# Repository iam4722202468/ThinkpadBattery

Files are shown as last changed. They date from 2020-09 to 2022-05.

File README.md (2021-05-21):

# ThinkpadBattery
Open source Thinkpad battery design

## What is this?

This is a fully open source laptop battery design. The design uses an attiny85, which can reply to the T420 motherboard's SMBUS requests.

## Setup

### Configurable Constants

- BATTERY_CAPACITY | Your battery capacity in mAH
- V_HIGH | The highest output voltage of your battery, normally 12.6v
- V_LOW | The cutoff for when the battery will stop working, normally around 10.8v

### Creating your own

Parts Needed
- Arduino Uno/Mega  (for programming the attiny85, Mega needs different pin assignment)
- 12v Lithium-Ion battery pack
- 3S Lithium-Ion BMS (it might be possible to use the existing bms if specification is available but communication needs to be implemented)
- Components from schematic
- PCB from schematic

Once you have all these parts, assemble the pcb and attach a BMS to your battery pack. Solder the 12v battery output/input to the large pads on the pcb, then program the attiny85 with the included ino file. The output pins at the bottom of the PCB are a 1-1 mapping of the motherboard pin input.

### Debugging

- The laptop won't supply power to the board unless it detects there's a battery attached, meaning if you plug the board in to the battery without having an external battery to power it, it won't work.

### Libraries

Use the ATTinyCore for compiling. Without it, Wire.h won't work.

## Limitations

### Voltage Reading / Remaining battery

Currently remaining battery %'s aren't exact because I'm assuming there is a linear coorelation between voltage and capacity (Which is wrong). This is probably fixable using a battery gas gauge, I'll have to investiage more.

### MCU Power Consumption

By design, the MCU will always be on as long as a battery is connected to it. This can cause the battery to slowly run out of power if it isn't connected to a laptop. A potential fix could be to implement a low power mode for the attiny, or have a seperate disconnect switch for the battery power on the battery pack itself.

### 3D Printable Case for T420 only

The case for the cells has been completed. The case model and stl files are included in /model

## Future Plans

iam4722202468 - Design and manufacture a PCB with current,voltage and battery capacity measuring capabilities, an easily programmable microcontroller, and a 3s balanced charger

pj1976 - Find a bms that would fit, or try to talk with bq29312pw that was in the original pack

## Credits

iam4722202468 - Initial work, T420 9 cell model

pj1976 - Added support for R50

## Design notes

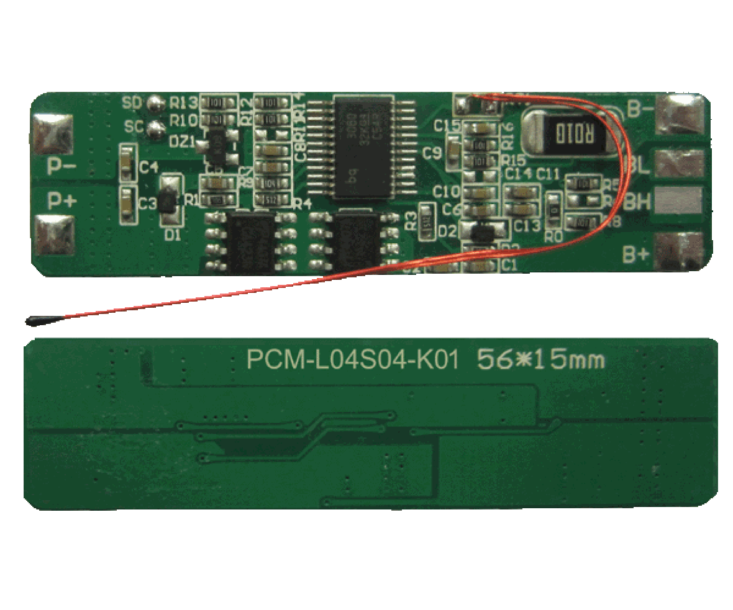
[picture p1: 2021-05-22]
KiCad/bq3060/references/r1.gif

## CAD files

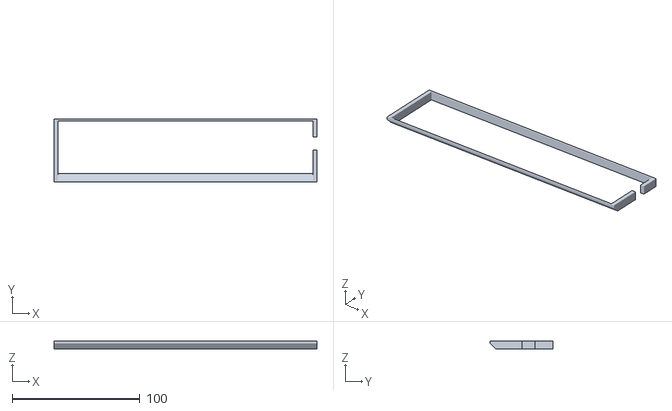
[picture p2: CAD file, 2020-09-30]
model/top_case_long.stl
206.0 x 49.0 x 6.50

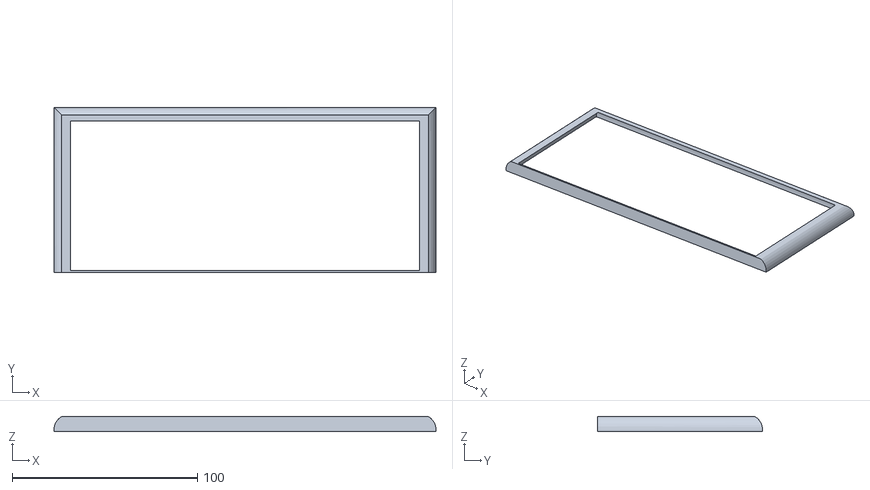
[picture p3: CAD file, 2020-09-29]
model/bottom_case_long.stl
206.0 x 89.0 x 8.00

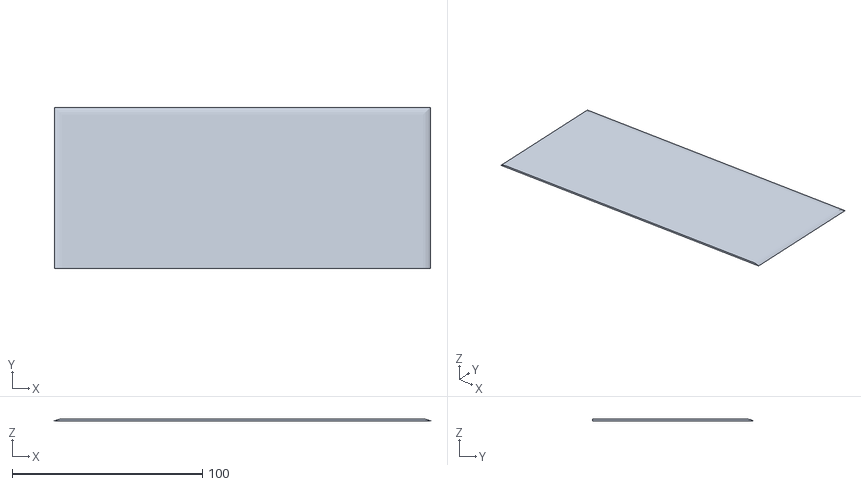
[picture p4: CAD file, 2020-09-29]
model/bottom_case.stl
197.7 x 84.9 x 1.00

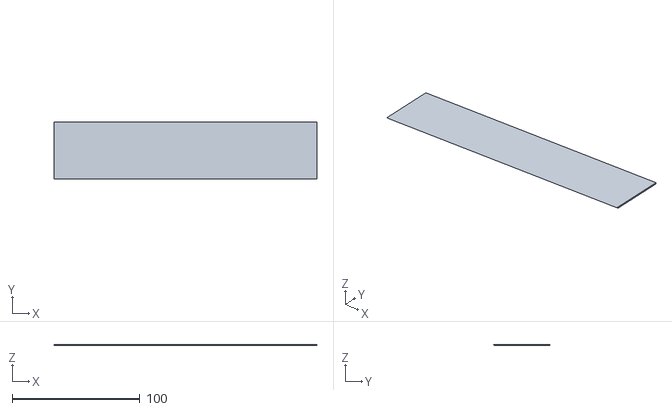
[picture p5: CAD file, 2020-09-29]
model/top_case.stl
206.0 x 44.5 x 1.00

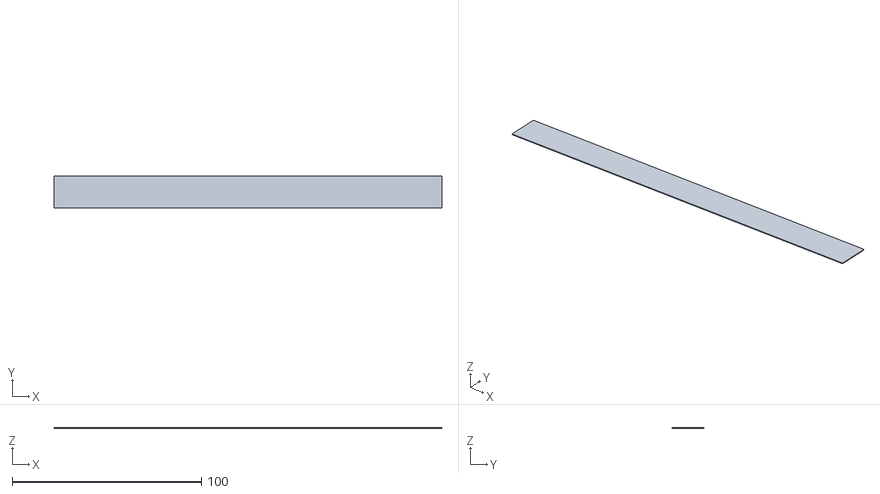
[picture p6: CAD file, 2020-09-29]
model/bottom_holder_thin.stl
205.0 x 17.0 x 0.4

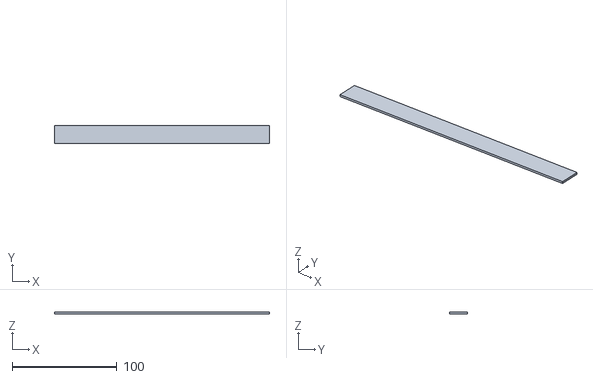
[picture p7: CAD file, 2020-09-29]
model/bottom_holder_thick.stl
205.0 x 17.0 x 1.60

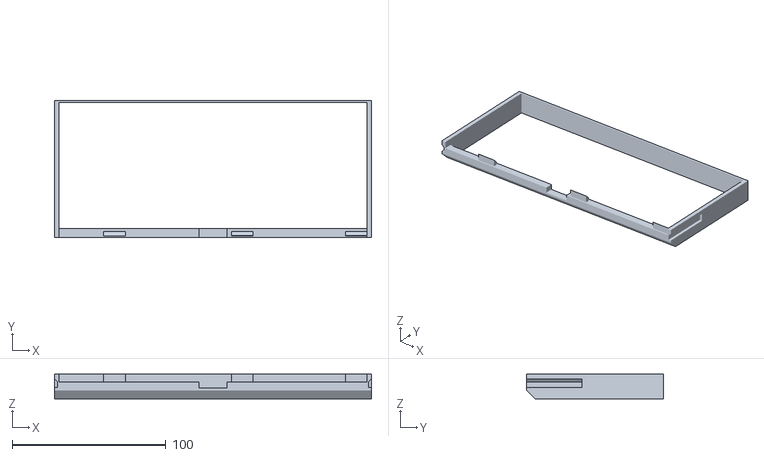
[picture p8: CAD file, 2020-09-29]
model/back.stl
206.0 x 89.0 x 16.0

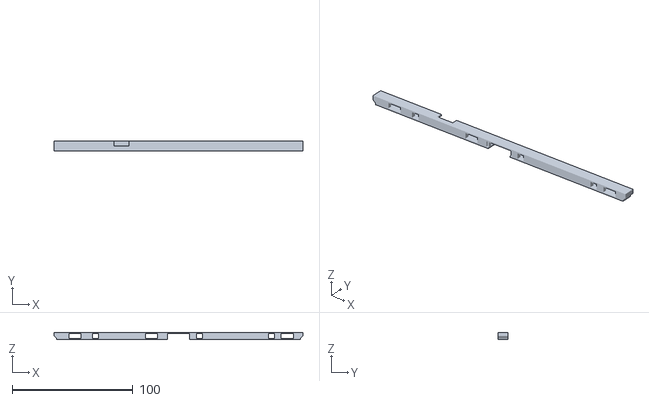
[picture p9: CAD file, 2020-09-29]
model/front.stl
206.0 x 8.00 x 6.00

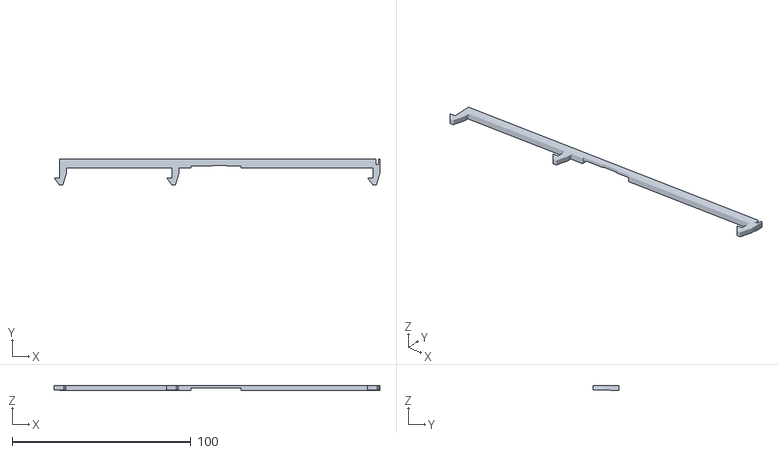
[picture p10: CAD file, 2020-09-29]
model/lock.stl
182.5 x 14.5 x 3.00

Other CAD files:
model/case.FCStd

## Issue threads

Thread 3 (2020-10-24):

Problems verifying .ino sketch

develroo, 2020-10-24:
Hi. First I want to say thanks very much for this project because it fits my need almost perfectly. I am trying to emulate a battery to power a laptop by a DC power supply. Once you have a suitable resistance for Thermal overload it will power on and stay on so long as the OS is not fussy about battery status and power down thinking the battery is broken. This is where your project comes in.

However I downloaded your batteryEmulator.ino but it fails to verify or compile

```
Arduino: 1.8.13 (Linux), Board: "Digispark Pro (Default 16 Mhz)"

/home/user/devel/git/ThinkpadBattery/batteryEmulator/batteryEmulator.ino: In function 'void setup()':
batteryEmulator:523:19: error: no matching function for call to 'USI_TWI::begin(int)'
   Wire.begin (0x0B);
                   ^
/home/user/devel/git/ThinkpadBattery/batteryEmulator/batteryEmulator.ino:523:19: note: candidate is:
In file included from /home/user/devel/git/ThinkpadBattery/batteryEmulator/batteryEmulator.ino:1:0:
/home/user/.arduino15/packages/digistump/hardware/avr/1.6.7/libraries/Wire/Wire.h:57:13: note: void USI_TWI::begin()
     void    begin();
             ^
/home/user/.arduino15/packages/digistump/hardware/avr/1.6.7/libraries/Wire/Wire.h:57:13: note:   candidate expects 0 arguments, 1 provided
batteryEmulator:524:8: error: 'class USI_TWI' has no member named 'onReceive'
   Wire.onReceive (receiveEvent);
        ^
batteryEmulator:525:8: error: 'class USI_TWI' has no member named 'onRequest'
   Wire.onRequest (requestEvent);
        ^
exit status 1
no matching function for call to 'USI_TWI::begin(int)'

This report would have more information with
"Show verbose output during compilation"
option enabled in File -> Preferences.

```

I don't know much about your environment but am I missing something in mine?

Edit: For reference I do include the TinyWire lib.

```
#include <USI_TWI_Master.h>
#include <TinyWireM.h>

#include <Wire.h>
```

Thanks

digmorepaka, 2020-10-24:
try using wire.h only and attinycore instead of digistump. i had this same issue and that resolved it

iam4722202468, 2020-10-30:
digmorepaka is correct, based on your error log it looks like you need to use attinycore.

develroo, 2020-11-03:
Yeah fixed and I compiled the code alas it was not a drop in replacement for my battery/laptop. I don't have the time to reverse engineer the protocol unless you can do it with the batter alone because I have already seconded the laptop into it's 1U case and put it in the cabinet. I can still boot Linux so long as I use `acip=off` which is ok but that also affects the fans if I am not very much mistaken so.

Wish I had the time and tools to debug the communication but alas I have neither atm.

Thanks anyway it is a great resource and I will think about getting a data analyser anyway just for the next time I run into something like this.

Cheers!

Closed 2020-10-30.

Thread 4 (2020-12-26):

universal battery emulator?

5ch4um1, 2020-12-26:
Hello young gentleman!
First of all, thank you very much for your excellent work!
I was wondering if you realize that your sketch is basically an implementation of the SBS for arduino? I mean, Thinkpads are by far not the only devices that use TI controllers, and your sketch should be really easy to adapt to other arduino platforms and most important: other batteries and devices!
I did some first tests today, it seems to crash when you ask for and address that is not defined, but most of the things my laptop wants to know are already defined. btw, any interest in maybe making a wiki with explanations for all the values? like, 3b-3f looks like cell voltages,  1c is the serial number, etc... i was going to read some pdfs again these days that start with sluu, but wouldn't it be nice to have this information in a more human readable format, without all the scrolling, like a simple table maybe? I was able to capture the communication with my dead but still talking ideapad battery, so i know what it will be asking for.
The ability to simply make up certain values seems very practical for testing!
I was wondering, how do you tell the system that a battery is present, when it's not? resistor between + and - should do i guess?
And how about adding a temperature sensor instead of hardcoding 22,1 ºC, i mean, it's an arduino? And maybe add some logic that doesn't charge when the temperature is too high?

iam4722202468, 2021-01-18:
Hey!
Yeah, this is basically an implementation of the SMBus for an attiny controller. Thanks for letting me know about the crashing, about a week ago I was thinking about this code and realized that crashing might have been a problem when it got requests that weren't defined, but wasn't sure.

> I was wondering, how do you tell the system that a battery is present, when it's not? resistor between + and - should do i guess (edit: seems like a 10kohm resistor between the thermistor and ground does the trick.)

Sounds right. Interestingly, I noticed that the cheap third party battery I took apart uses a 10k resistor on the temperature sensor pin too.

> And how about adding a temperature sensor instead of hardcoding 22,1 ºC, i mean, it's an arduino? And maybe add some logic that doesn't charge when the temperature is too high?

Another good idea, it would definitely be possible, would be easy to add, and there's free pins that aren't used for anything on the attiny right now.

The long term plan is to make this an open platform for all old batteries, where there's one pcb that can be programmed to work with any laptop. Right now I'm taking a bit of a break from this project while I wait on a bunch of attiny pcb's to be manufactured, once those come in I'll continue doing more testing. Have learned a lot about this since I started the project, hopefully I'll be able to expand on what I've already posted soon.

5ch4um1, 2021-01-19:
Well, also not limited to attiny, i tried with an arduino nano clone and it worked, and i could imagine that this will work on a lot of other platforms too ;)
And for the temperature sensor, "A thermistor is a temperature sensitive resistor..." so 10kohm means something around 21º C iirc. Would probably be possible to recycle one from an old battery pack and use it with the microcontroller.
I wonder if the temperature is measured by both the battery and the laptop? I mean, the battery for sure, but the laptop has that pin, so i guess it somehow uses it?
Anyway, i'd definitely recommend to keep a simple version around as the project grows, for educational and testing purposes it seems very practical as it is at the moment.
speaking about old batteries, do newer devices have some kind of authentication mechanism for normal operation mode?
Newer devices seem to have secure auth to get them into unsealed or full access mode, but i haven't heard of anything like this for normal operation mode?
Anyway, there is a huge potential in this, this is literally power to the people!
thank you very much.

iam4722202468, 2021-01-20:
> do newer devices have some kind of authentication mechanism for normal operation mode
Yeah, this is a bit of a problem, quite a few devices require the correct reply from the auth command. The T430 actually has an auth command, where an incorrect reply will stop the battery from charging.

One of the benefits on using an attiny instead of a conventional SMbus IC is that they're easy to program, and in the future if exploits or workarounds are found for the auth sequences it's super easy to update and test the code. Some manufactures also implement custom commands, and again for the same reasons using an attiny here can simplify things.

TheWorldIsBetterWithElectronics, 2021-07-23:
Hello,
This is a very interesting project. You did a hell of a job. Thanks you. But could you reediter the code with a little more comments so that it is more understandable because I am not a code genius. Because I would like to modify the project so that it adapts to my computer but I quickly get lost in all these lines. Thank you if you have some time to help me to understand the code.

iam4722202468, 2021-07-23:
@TheWorldIsBetterWithElectronics
> Hello,
> This is a very interesting project. You did a hell of a job. Thanks you. But could you reediter the code with a little more comments so that it is more understandable because I am not a code genius. Because I would like to modify the project so that it adapts to my computer but I quickly get lost in all these lines. Thank you if you have some time to help me to understand the code.

Thanks for the feedback! I added some comments to explain what's going on in the code, hopefully that helps you.
For future reference, it's generally better to create a separate issue for new requests as it makes it easier for the developer to find the message and helps you more easily track work done.

TheWorldIsBetterWithElectronics, 2021-07-23:
Thanks for the improved code feedback, it's still easier to understand the big parts of the code now. I will continue to experiment with the battery of my computer and I will tell you if it works or not. I will probably come back to ask questions but now, I will not forget to create a new  issue . Thank you very much.

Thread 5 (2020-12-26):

gap between request and answer?

5ch4um1, 2020-12-26:
Not a real issue, seems to work anyway, i just noticed that the arduino takes a bit longer to answer (roughly 420 microseconds) than the original battery, here the arduino (nano clone):
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

and here the original:

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
is that maybe the time it takes to calculate the pec, or why is this happening?

digmorepaka, 2020-12-27:
Not sure if it's related, but apparently if you have the Arduino bootloader flashed the atmels tend to be slower in certain operations, does this occur when flashing the compiled binary over icsp while ommiting Arduino bootloader etc

5ch4um1, 2020-12-27:
you mean cross compiling it with avr-gcc and flashing it with avrdude? no, haven't tried this yet. and actually this looks a bit complicated for the newbie that i am. and again, it works anyway, the delay seems to be within what's acceptable for the laptop.
I think i have like a million questions, is there maybe a thread in a forum, subreddit, discord, or anything like that?
Anyay, i tested today with my Ideapad G550 and so far it seems to work pretty much "out of the box", though it won't accept any other vendor name than the original, defaults to COMPAL otherwise:
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

iam4722202468, 2021-01-18:
Haven't done any testing for this yet, but if the delays are consistently the same length for all the packets I suspect the attiny is just taking a while to process the input and create the output.

iam4722202468, 2021-01-19:
@5ch4um1 if you want to ask questions, I'm on the thinkpad discord with a bunch of other people who would be happy to answer them! https://discord.com/invite/Ybdz7AS

5ch4um1, 2021-01-19:
Thanks again, very much appreciated.
And i don't know, i tested with an arduino nano clone, could test now again with a wemos d1 mini, don't have a second logic analyzer to see if maybe something was wrong with that part of my setup, but as mentioned, it works anyway. I may or may not have posted this issue just to point out that the gap was 420 microseconds... ;)
Closing for now, will reopen if it turns out to be a real functional issue.

Closed 2021-01-19.

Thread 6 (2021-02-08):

Help me please. The voltage of 12367mV is displayed all the time, it always shows 100% of the charge

Naughtydog2004, 2021-02-08:
Hello. Can you please tell me which command controls the battery state of charge at 100% and charge / discharge mode? I can manage charge percentages with the byte reply0x0D command. But my laptop still shows 100% and won't charge the battery. By the way, the voltage from the resistor divider also does not change in any way and is transmitted to the SMBus as 12367mV (although, separately from this program, the code for measuring the voltage functions properly through the analog pin A3 on the arduino nano). Thanks in advance.
https://drive.google.com/file/d/1x5DdUYXAxN2JYD1_1s9keKdGmnjLt5Kj/view?usp=sharing

iam4722202468, 2021-02-10:
Looking at my code, it looks like reply0x0F is what handles the % charged, try manually setting the charge value to something and checking if that changes the charge of your device. If it doesn't, then your device might need other packets than just the 0x0D one. Not all implementations of the smbus are identical for all devices

iam4722202468, 2021-02-10:
As for the voltage divider, there's a chance I screwed something up and it doesn't actually work, really hoping that isn't the case though... either way, i'll probably redo a few parts of this in around 4 months from now. The idea is to make a small pcb with a 3s bms and attiny combined, that can be programmed for any device.

Naughtydog2004, 2021-02-10:
Thank you! If I can fix this, then I will inform you

luketimothyjones, 2022-05-13:
I think `0x0f()` is incorrect, unless the Thinkpad battery departs from the SMBus spec (which is entirely possible). Command `0x0f` is `RemainingCapacity()`, which is expressed as mAh or mWh depending on the value of `0x03` bit 15 (aka `CAPACITY_MODE`): `0` for mAh and `1` for capacity/10 mW/mWh. The calculation in `0x0f` is identical to `0x09` (`Voltage()`)above it, perhaps it was a copying mishap?

iam4722202468, 2022-05-14:
@luketimothyjones yes this does look like an issue. When making this I didn't really know what I was doing, and it looks like I did just copy it. Feel free to pr a fix

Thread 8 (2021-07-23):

Add comments to batteryEmulator.ino

iam4722202468, 2021-07-23:
The code may be hard for some people to understand, comments would be helpful to have.

iam4722202468, 2021-07-23:
Fixed in commit a405590499ceca53eaf2dc03386848951c07be7e

Closed 2021-07-23.

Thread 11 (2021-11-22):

SMBUS Communication Stops Wehn Grabing Battery Vender on Emulated Battery

Sam64-png, 2021-11-22:
Hi, I am trying to power a A485 think pad from my lab bench power supply and uploaded this code onto an Arduino Nano. I have it all wired correctly and it successfully communicates with the Arduino. I changed the battery reference voltage to 5 volts, set the analog pin to A3 and A3 is reading around 4.4 volts. When powering the laptop it never turns on but some of the i2c commands and found that it never gets to the point were it reads the voltage but stops once it reads the vender. Here is a log of all the commands sent.
`0x03 0x15 0x18 0x19 0x1A 0x1B 0x1C 0x20`. I kept the vender in the code to the default value "HACKED". I do not have a good way to test the laptop on a working battery. What happened is that its charging circuitry got destroyed so I had to desolder some parts for it to come on. Now when i plug in a almost dead battery it turns on but dies a few seconds later.

Also I tired to get the vender from the original battery but it seems to reply with 0xFF for everything.

I have to thank you a lot seance this code is a life savor seance i don't want to spend a lot of money to get a new one and I don't like throwing out a whole computer when only one part fails. I really hope you can help. Once i get this done i plan to make a custom pc with it and a type c connector and battery to get a lot of the old functionality back.

iam4722202468, 2021-11-24:
Please keep in mind that batteries are dangerous, and this project is meant to be used with a bms, it is not a replacement for a bms. If you're directly connecting the cells to the circuit that could be the problem

Sam64-png, 2021-12-01:
>

Sorry I probably did not explain it too well. I was using the project without any battery so I could power the laptop from a bench power supply threw the battery connector. I tied the battery voltage detection analog pin to a adjustable voltage reference for testing.  Also in the mean time I am assuming the laptop stops communicating with the battery because it may be checking the vender id to stop agent cheaper off brand batteries. I been trying to get the vender id from a preexisting think-pad battery using the same commands from the code. It responds to that IC2 address but always replys with 0xFF. I don't have a logic analyzer directly intercept its communications so i may have to wire something up there. If you know what is wrong in the arduino code causing this setup or model of laptop to mess up any help is greatly appreciated.

iam4722202468, 2022-01-04:
@Sam64-png Sorry for taking so long to reply!

You are correct in saying that some batteries expect verification codes, it looks like the A485 model came out recently and most laptops newer than the T420 series do have verification. The verification will not be possible to get around without some exploit or a modified EC firmware, and I don't think either of those exist for that laptop (yet).

The reason you can't simply send the same responses is because the motherboard most likely sends the battery a challenge-response test, which involves a message being sent from the motherboard to the battery, the battery signing the message with a private key, and the motherboard verifying the signature with a public key. Without the private key there's no way to get the battery to charge

I'm sorry to hear that your charging circuitry got destroyed, that's unfortunate.

There's a chance that the program is crashing, this can happen with the motherboard sends a packet type that isn't recognized. You could check this by using an arduino with serial output like an arduino uno, modifying the code to log the packets that it receives, running the code and checking if there are packets sent that don't appear in the code. That being said, even if you get a little bit more communication working between the battery and the motherboard you will never be able to get past the auth sequence.

Good luck with your future projects!

Sam64-png, 2022-01-04:
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

Alright sounds good. I expected something in that case seance I felt they would of changed that later on so people buy the more expensive batteries. I went ahead and got a new laptop. Idk if I trust the chargers or at least the old one I had because i am wondering if that is what caused the issue with the charging in the first place. I had one break a while back and never investigated why it was broken seance their assembled into a solid brick, but I wonder if it was caused by the capacitors going bad and it is generating an unfiltered output with voltage spikes. Thank you for the help.

luketimothyjones, 2022-05-02:
> There's a chance that the program is crashing, this can happen with the motherboard sends a packet type that isn't recognized.

For historical reference, this was resolved by #12

Closed 2022-01-04.

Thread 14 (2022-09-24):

PLEASE MAKE FOR LENOVO X220

jakevin99, 2022-09-24:
I am planning to recell my 9 cell x220 battery but problem is the chip inside.

iam4722202468, 2022-10-07:
This will probably work on the x220 without any changes

iam4722202468, 2023-11-27:
> But will it work on **30 models?

Nah, unmodified the **30 models use a signature packet between the battery and laptop to ensure the laptop is authentic. No way around this, as message replies cannot be validated without having the key. There is [this](https://github.com/hamishcoleman/thinkpad-ec) project which you can use to remove the signing and make the battery work.

Michal-Szczepaniak, 2023-11-27:
What if i have corebooted **30 model? Then it will work?

iam4722202468, 2023-11-27:
Coreboot itself is only a modification for the bios. The EC (Embedded Controller) is what communicates with the battery, and is what needs to be modified.

Michal-Szczepaniak, 2023-11-27:
gotcha

Bromiun, 2023-11-28:
Isn't there a practical way to get around this problem?  A pack is usually 3S2P.  And let's say you have 6x 18650s to replace.

Charge the pack and 6 good cells to full.  Solder (with wires) 3S of the good cells to the existing two power strips and two balance strips in the pack.  This will keep the handshake trap happy.

Remove 3S of the bad cells.  Replace with good cells.  Either soldered or spot welded.

Remove the 2nd set of 3S bad cells and replace with the first 3S of good cells.

I believe that it is sufficient for one cell to go bad, to make the battery pack useless.  So test the 6 bad cells and you may find a few still operational.

iam4722202468, 2023-11-28:
That is possible, but it requires having a working battery. The goal of this project is to create a working battery from scratch.

Bromiun, 2023-11-29:
Yes, a valid point.  During my 15 years having multiple ThinkPads, I have accumulated a lot of packs with bad cells.  Buying packs off eBay is a possibility and my last purchase I believe about $50 is fantastic.  I used to open the packs up and replace the cells straight.  I soon discovered that is a good way to destroy a pack.

At one time, the laptop male connector got misaligned, and due to a defect in the design, when you push in the battery, it even clicks giving you a false sense that connection has been made. I could not get any pack to work and there was no mention of this issue in any forum.  I went through 3 or 4 packs the discover the problem and simple aligned the connector and it has been working to this day.. So I have a few working packs.  The design problem is that the female connector on the pack is spring loaded.  So it does not have to mate with the male terminal to insert the pack, and you can still push it in and force a false positive click.

I am sure you can find cheap packs that have bad cells but are still alive.  Have you tried this?

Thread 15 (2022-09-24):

Arduino Uno pack

Bromiun, 2022-09-24:
Hi Iam, I am new to Github, so am not sure how to connect with you.  This may not be the correct manner.  Please let me know.

I want to connect my 3s5p 2170 pack to my T540.  This will be in a box along with an Uno, separate from the laptop.  There will be no PCB.  There may be a 2x40 LCD to report on usage, V, Wh, etc.  No need to inform the T540 on the status.  BMS and protection and charging all in the box.  This will be the simplest method to defeat Lenovo's anti-consumer lock.

I need to figure out how to connect the Uno to the Thinkpad.  I am assuming that after the handshake, the Uno can can go to sleep?

If I connect the I2C bus, and the Gnd and Vcc to B+ and B-, download your software, will this do the job?  In which case I only need a female connector, or even could hardwire that.

Before I start this project, I need your blessing and help.  Thank you so much.

Brom
Brom dot Nader at gmail dot com

iam4722202468, 2022-10-07:
Hey,

Yes, github is a great way to connect with project owners (: I only check this project occasionally, but I will eventually see issues posted here.

The T540 batteries use a key signing process that can't be defeated without the private keys on the battery, which as far as I know nobody has access to. This means that unfortunately, this project won't work with it. This is the case for anything newer than the **20 series, with the **30 series having a project that lets you rewrite the embedded controller found [here](https://github.com/hamishcoleman/thinkpad-ec)

With an older, supported laptop (anything before and including the x220, T420, etc.), the project would be connected to the battery connector. The battery itself uses I2C over the connector pins, like this
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

When the laptop is on, it's constantly communicating with the battery for information like remaining capacity, voltage level, temperature, etc. and from what I've seen, if these packets aren't received or the checksum is wrong, the laptop will go through the handshake process again.

Bromiun, 2022-10-25:
>
Thank you for your reply, which I just have seen. As you say, the private key (of laptop or pack?) is in the pack.  So how do the Chinese clone makers manage to make clones?

Also, my female connector leads look different than the image you have.

BTW, a couple years back, for a long time, the W540 refused to recognize legitimate packs.  I kept on ordering new clones, and still they were not recognized.  After spending a lot of time on this, I realized the problem was that the male and female connectors did not line up and mate exactly, as the male leads were bent, so there was no proper contact.  You would think that if this happens, the pack should not click in place and laptop would resist insertion of the pack.  Turns out the female connector on the PCB in the pack has no backing.  You can easily push the female connector in, so no mating was necessary for the pack to click in!  Imagine if I had ordered expensive Lenovo packs, and they would still have this problem.  Very bad design.

 I had a 3S3P clone battery, with only 10 minutes of juice remaining for the Lenovo W540.  So I opened it up.  Soldiered 3S to the 4 leads to keep the power on, and then carefully removed the 9 cells.  The cover said 7.8 Ah.  But each cell says 2.2 Ah, so a total of 6.6 Ah.  Quite a scam.  Moreover,the cells were Chinese made, even though the model number was like a Korean cell.  Most of the cells tested at 0.7 Ah, and some as low as 0.12 Ah, even though they could hold a 4V charge.

After building a 3S3P with Panasonic NCR18650B (3.4 Ah), I carefully inserted cells and soldiered the leads.  In this process one of the two balance leads got detached and lost its power for a short while.

Now the W540 recognizes that there is a pack there, but refuses to charge it and Windows shows a black cell icon.  I rebalanced the cells but that made no difference.  When I disconnect power, the laptop remains on for 20 seconds, and then it looks like it is going to sleep with gradual dimming.  But does not awake.  When power is connected, it reboots from scratch.

iam4722202468, 2022-11-06:
I'm not sure how the Chinese clones work, but for newer models they must have somehow gotten the key from an authentic battery pack, which isn't possible for us to do.

Recelling packs is definitely a good choice, although I'm not sure what exactly happened to your pack. You could check the laptop on Linux and see if has the same behavior, but my guess is there's an issue with the pack's bms which probably isn't solvable.

auroraanna, 2025-01-08:
if working battery packs have the private key on a flash chip separate from their microcontroller, you can probably sniff on the pins between the microcontroller and the flash chip for the private key

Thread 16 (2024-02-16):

The laptop part of the circuit

exander77, 2024-02-16:
Hello, I would like to use ThinkPad battery to charge feed power to Raspberry Pi and ability to charge the battery, can you offer any support with this? Or point me in the right direction?

Bromiun, 2024-02-17:
No need for thinkpad battery.  Just buy two 18650 lithium ion batteries.  Connect them serially and that is about 8.4 volts. Use this to power the Rasberry pie.

To charge, get a 9 V DC power supply.  Put one 1 amp diode in series with positive terminal.  Measure voltage.  It should be 8.4 volts.  Put a 1 ohm resistor in series with the diode.  This is now your charger for the two batteries in series.

Each diode drops the voltage by 0.6 V.  If the power supply is higher than 9 volts, put several diodes in series so it drops down to 8.4 volts.

If you want longer battery life, get two more 18650, and connect each in parallel with the two that are in series.

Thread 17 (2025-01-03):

CRC Checksum

lokeb, 2025-01-03:
Hi. Would you care to share how you got the checksum routine? TI’s documentation uses a CRC-8 checksum.

I am trying to build it for a Lenovo battery pack of 16.8 V.

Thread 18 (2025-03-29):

status update, BQ working?

UltraBlackLinux, 2025-03-29:
Hey there,
what's the status looking like for this project, specifically with the BQ chip? Is that still in the prototyping phase or perfectly usable and working already?

Thanks!

iam4722202468, 2025-05-06:
It's still a WIP but it's 95% complete. I don't know enough to make any further progress. The design closely follows the reference design, if someone's looking to complete the schematic + PCB that would be a good place to start

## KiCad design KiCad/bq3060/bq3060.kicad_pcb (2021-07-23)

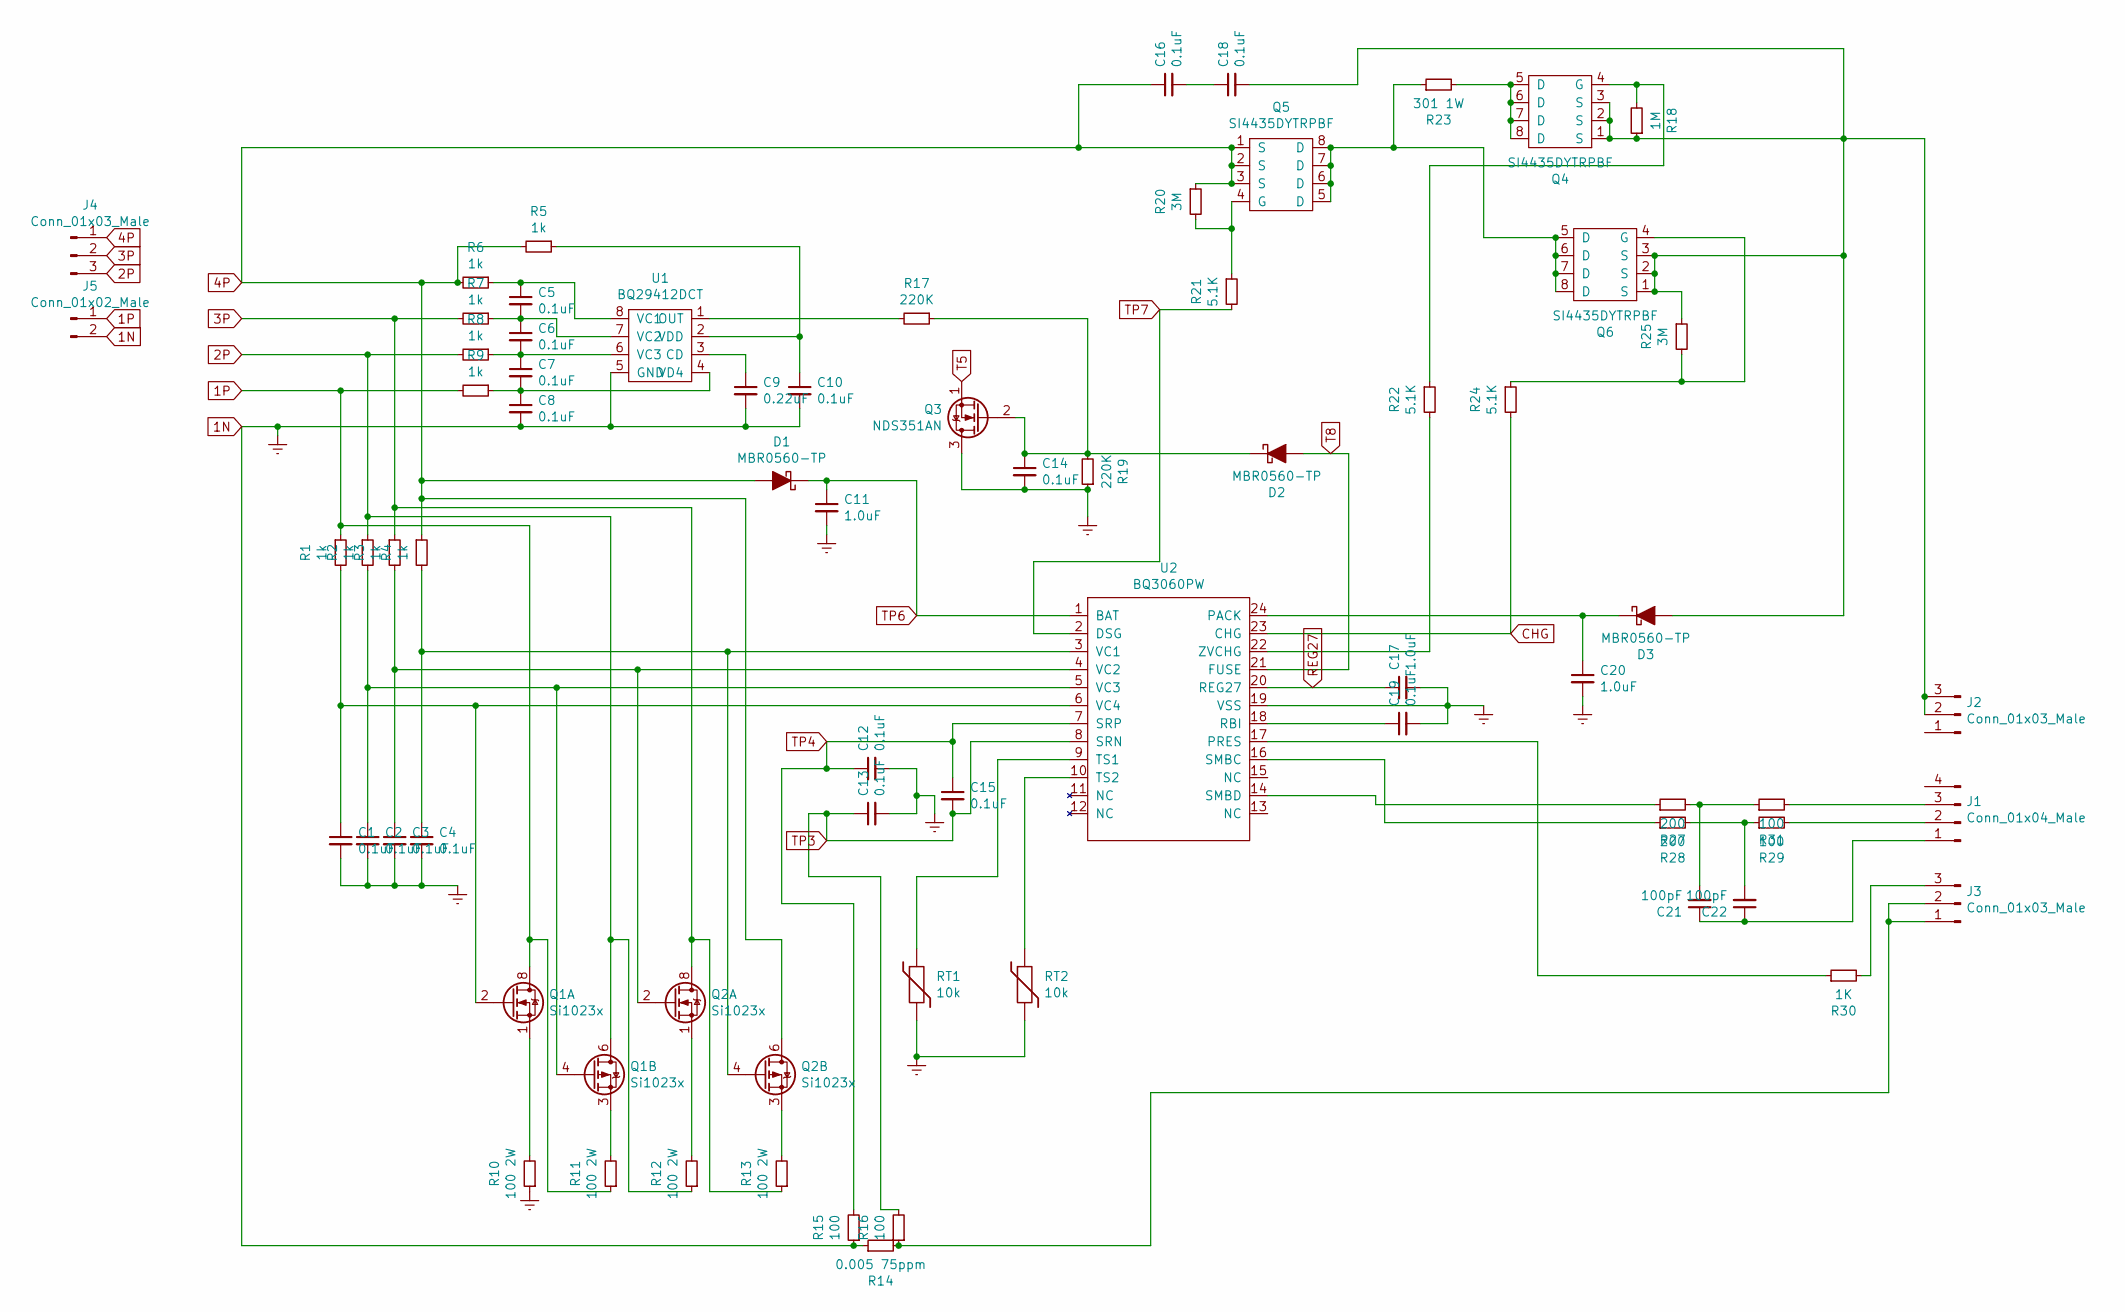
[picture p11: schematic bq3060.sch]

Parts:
C1, C2, C3, C4, C5, C6, C7, C8, C10, C12, C13, C14, C15, C16, C18, C19: 0.1uF; C_0805_2012Metric_Pad1.15x1.40mm_HandSolder
C9: 0.22uF; C_0805_2012Metric_Pad1.15x1.40mm_HandSolder
C11, C17, C20: 1.0uF; C_0805_2012Metric_Pad1.15x1.40mm_HandSolder
C21, C22: 100pF; C_0805_2012Metric_Pad1.15x1.40mm_HandSolder
D1, D2, D3: MBR0560-TP; D_SOD-123
J1: Conn_01x04_Male; PinHeader_1x04_P2.54mm_Horizontal
J2, J3: Conn_01x03_Male; PinHeader_1x03_P2.54mm_Vertical
J4: Conn_01x03_Male; SolderWirePad_1x03_P5.715mm_Drill2mm
J5: Conn_01x02_Male; SolderWirePad_1x02_P7.62mm_Drill2mm
Q1, Q2: Si1023x; SOIC-8_3.9x4.9mm_P1.27mm
Q3: NDS351AN; SOT-23
Q4, Q5, Q6: SI4435DYTRPBF; SOIC-8_3.9x4.9mm_P1.27mm
R1, R2, R3, R4, R5, R6, R7, R8, R9: 1k; R_0805_2012Metric_Pad1.15x1.40mm_HandSolder
R10, R11, R12, R13: 100 2W; R_2512_6332Metric_Pad1.52x3.35mm_HandSolder
R14: 0.005 75ppm; R_2512_6332Metric_Pad1.52x3.35mm_HandSolder
R15, R16, R29, R31: 100; R_0805_2012Metric_Pad1.15x1.40mm_HandSolder
R17, R19: 220K; R_0805_2012Metric_Pad1.15x1.40mm_HandSolder
R18: 1M; R_0805_2012Metric_Pad1.15x1.40mm_HandSolder
R20, R25: 3M; R_0805_2012Metric_Pad1.15x1.40mm_HandSolder
R21, R22, R24: 5.1K; R_0805_2012Metric_Pad1.15x1.40mm_HandSolder
R23: 301 1W; R_2512_6332Metric_Pad1.52x3.35mm_HandSolder
R27, R28: 200; R_0805_2012Metric_Pad1.15x1.40mm_HandSolder
R30: 1K; R_0805_2012Metric_Pad1.15x1.40mm_HandSolder
RT1, RT2: 10k; R_0805_2012Metric_Pad1.15x1.40mm_HandSolder
U1: BQ29412DCT; SN74LVC2G241_DCT_8
U2: BQ3060PW; TSSOP-24_4.4x7.8mm_P0.65mm

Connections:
1N: C1.2, C2.2, C3.2, C4.2, C8.2, C9.2, C10.2, C11.2, C12.2, C13.2, C14.2, C17.2, C19.2, C20.2, J5.2, Q3.3 (D), R10.1, R14.1, R15.1, R19.1, RT1.2, RT2.2, U1.5 (GND), U2.19 (VSS)
1P: J5.1, Q1.7 (D), Q1.8 (D), R1.1, R9.2, R11.1
2P: J4.3, Q1.5 (D), Q1.6 (D), R2.1, R8.2, R12.1
3P: J4.2, Q2.7 (D), Q2.8 (D), R3.1, R7.2, R13.1
4P: C16.1, D1.2 (A), J4.1, Q2.5 (D), Q2.6 (D), Q5.1 (S), Q5.2 (S), Q5.3 (S), R4.1, R5.2, R6.2, R20.1
CHG: R24.2, U2.23 (CHG)
unnamed: C1.1, Q1.2 (G), R1.2, U2.6 (VC4)
unnamed: C2.1, Q1.4 (G), R2.2, U2.5 (VC3)
unnamed: C3.1, Q2.2 (G), R3.2, U2.4 (VC2)
unnamed: C4.1, Q2.4 (G), R4.2, U2.3 (VC1)
unnamed: C5.1, R6.1, U1.8 (VC1)
unnamed: C5.2, C6.1, R7.1, U1.7 (VC2)
unnamed: C6.2, C7.1, R8.1, U1.6 (VC3)
unnamed: C7.2, C8.1, R9.1, U1.4 (VD4)
unnamed: C9.1, U1.3 (CD)
unnamed: C10.1, R5.1, U1.2 (VDD)
unnamed: C14.1, D2.1 (K), Q3.2 (G), R17.1, R19.2
unnamed: C16.2, C18.1
unnamed: C18.2, D3.2 (A), J2.2, J2.3, Q4.1 (S), Q4.2 (S), Q4.3 (S), Q6.1 (S), Q6.2 (S), Q6.3 (S), R18.1, R25.1
unnamed: C19.1, U2.18 (RBI)
unnamed: C20.1, D3.1 (K), U2.24 (PACK)
unnamed: C21.1, C22.1, J1.1
unnamed: C21.2, R27.2, R31.1
unnamed: C22.2, R28.2, R29.1
unnamed: J1.2, R29.2
unnamed: J1.3, R31.2
unnamed: J3.1, J3.2, R14.2, R16.1
unnamed: J3.3, R30.2
unnamed: Q1.1 (S), R10.2
unnamed: Q1.3 (1), R11.2
unnamed: Q2.1 (S), R12.2
unnamed: Q2.3 (1), R13.2
unnamed: Q4.4 (G), R18.2, R22.1
unnamed: Q4.5 (D), Q4.6 (D), Q4.7 (D), Q4.8 (D), R23.2
unnamed: Q5.4 (G), R20.2, R21.1
unnamed: Q5.5 (D), Q5.6 (D), Q5.7 (D), Q5.8 (D), Q6.5 (D), Q6.6 (D), Q6.7 (D), Q6.8 (D), R23.1
unnamed: Q6.4 (G), R24.1, R25.2
unnamed: R17.2, U1.1 (OUT)
unnamed: R22.2, U2.22 (ZVCHG)
unnamed: R27.1, U2.14 (SMBD)
unnamed: R28.1, U2.16 (SMBC)
unnamed: R30.1, U2.17 (PRES)
unnamed: RT1.1, U2.9 (TS1)
unnamed: RT2.1, U2.10 (TS2)
REG27: C17.1, U2.20 (REG27)
T5: Q3.1 (S)
T8: D2.2 (A), U2.21 (FUSE)
TP3: C13.1, C15.2, R16.2, U2.8 (SRN)
TP4: C12.1, C15.1, R15.2, U2.7 (SRP)
TP6: C11.1, D1.1 (K), U2.1 (BAT)
TP7: R21.2, U2.2 (DSG)

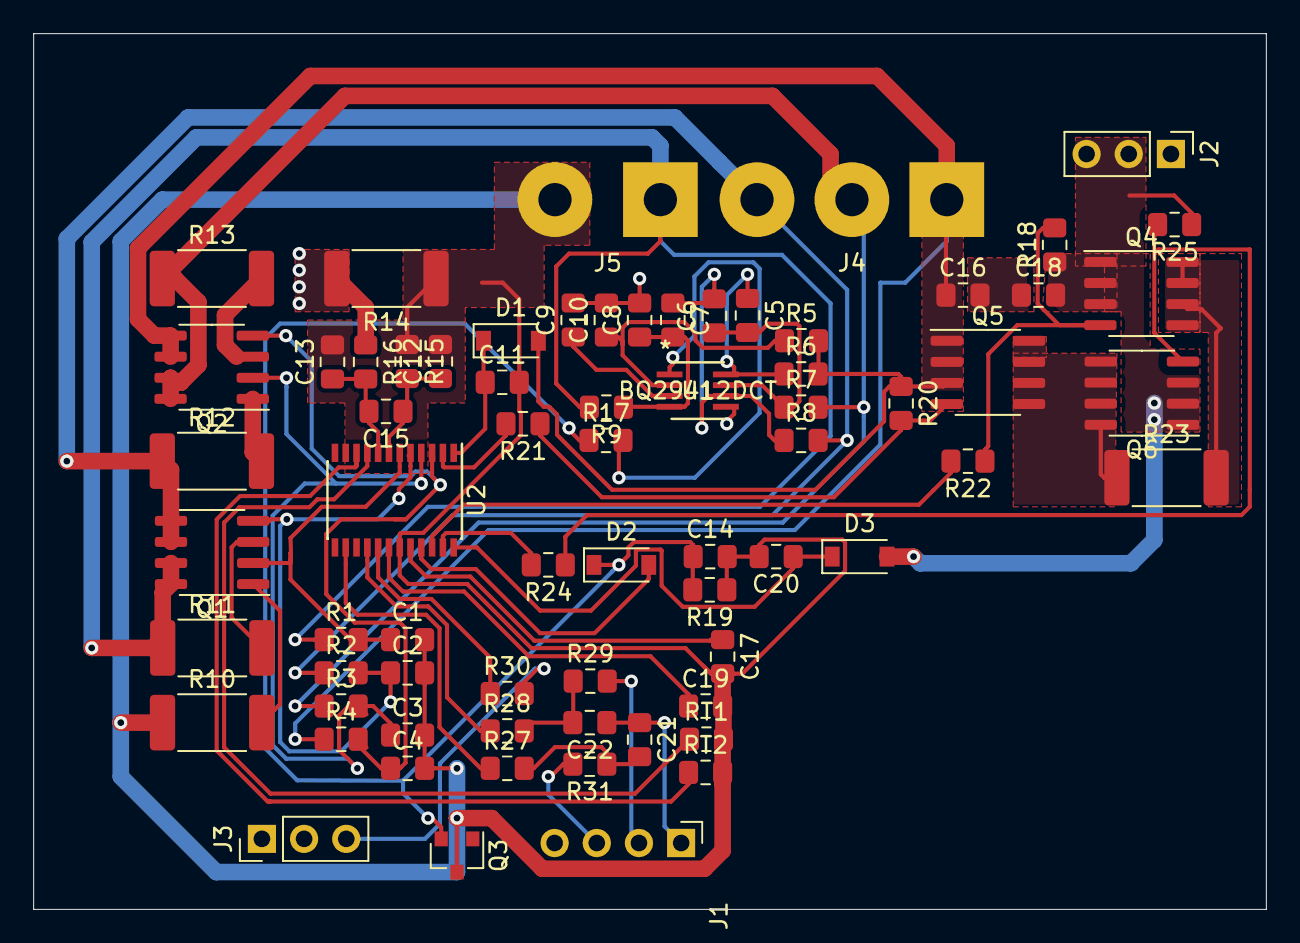
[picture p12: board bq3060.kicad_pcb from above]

Board: 2 copper layers, 74.2 x 52.8 mm, 70 parts (0 on the bottom side), 50 nets.

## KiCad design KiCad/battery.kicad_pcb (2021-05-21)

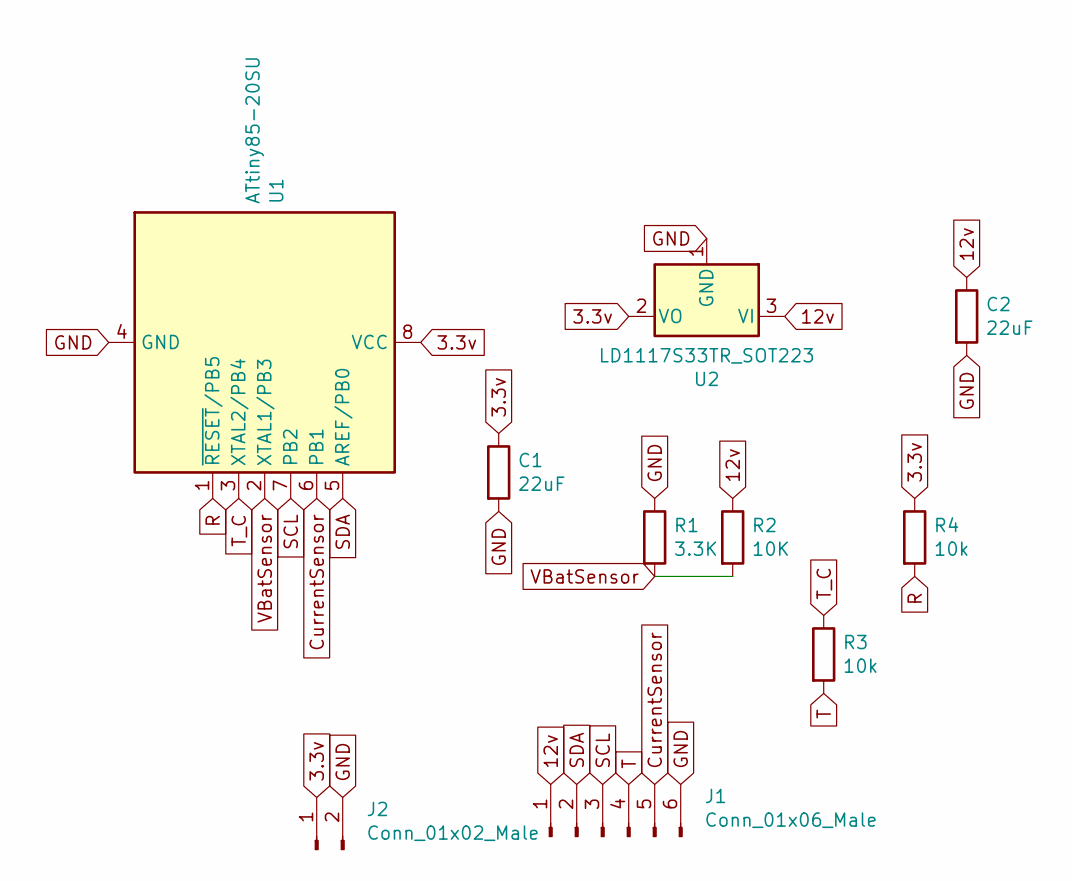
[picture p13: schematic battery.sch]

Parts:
C1, C2: 22uF; C_0805_2012Metric
J1: Conn_01x06_Male; PinHeader_1x06_P2.54mm_Horizontal
J2: Conn_01x02_Male; PinHeader_1x02_P2.54mm_Vertical
R1: 3.3K; R_0402_1005Metric
R2: 10K; R_0402_1005Metric
R3, R4: 10k; R_0402_1005Metric
U1: ATtiny85-20SU; SOIJ-8_5.3x5.3mm_P1.27mm
U2: LD1117S33TR_SOT223; SOT-223-3_TabPin2

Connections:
3.3v: C1.1, J2.1, R4.1, U1.8 (VCC), U2.2 (VO)
12v: C2.1, J1.1, R2.1, U2.3 (VI)
CurrentSensor: J1.5, U1.6 (PB1)
GND: C1.2, C2.2, J1.6, J2.2, R1.1, U1.4 (GND), U2.1 (GND)
R: R4.2, U1.1 (~RESET~/PB5)
SCL: J1.3, U1.7 (PB2)
SDA: J1.2, U1.5 (AREF/PB0)
T: J1.4, R3.2
T_C: R3.1, U1.3 (XTAL2/PB4)
VBatSensor: R1.2, R2.2, U1.2 (XTAL1/PB3)

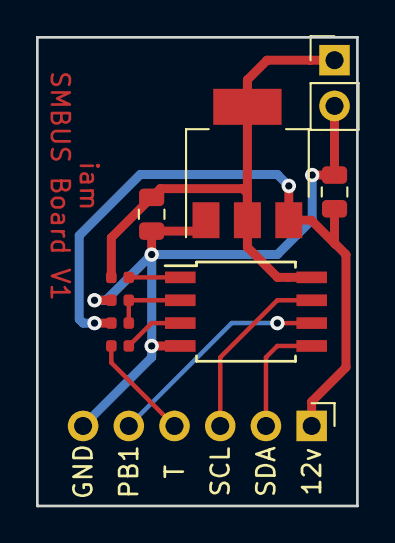
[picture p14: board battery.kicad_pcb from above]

Board: 2 copper layers, 17.8 x 26.0 mm, 10 parts (0 on the bottom side), 10 nets.

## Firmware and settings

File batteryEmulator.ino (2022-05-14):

#include <Wire.h>

// First 4 chars are cut off
#define BATTERY_MODEL "LNV-Version 2"
#define BATTERY_VENDOR "HACKED"
#define CHARGE_VOLTAGE 12600
#define BATTERY_VOLTAGE 10800
#define SERIAL 420

#define V_HIGH 12.1

// 20% above where the battery actually dies. This is because on load my T420 can pull the voltage down 20%.
// If you're using a non-modified T420 you can probably use 10.2-10.3 here and get 10% more battery life.
#define V_LOW 10.52

// mAh, uses BATTERY_VOLTAGE when calculating Wh
#define BATTERY_CAPACITY 15000
#define BATTERY_CAPACITY_DESIGN 15000

byte command;

// 0 - Charging
// 1 - Battery Powered
int mode = 1;

void splitNum(int num, int* upper, int* lower) {
  *lower = (num & 0xff00) >> 8;
  *upper = num & 0x00ff;
}

bool needsLength(int type) {
  return (type == 0x20 ||
      type == 0x21 ||
      type == 0x22 ||
      type == 0x23 ||
      type == 0x30 ||
      type == 0x3C ||
      type == 0x37 ||
      type == 0x2F);
}

void iterateCRC(bool CRC[8], int currentByte) {
  for (int y = 0; y < 8; ++y) {
    bool currentBit = (currentByte >> (7-y)) & 0x01;
    bool invert = currentBit ^ CRC[7];

    CRC[7] = CRC[6];
    CRC[6] = CRC[5];
    CRC[5] = CRC[4];
    CRC[4] = CRC[3];
    CRC[3] = CRC[2];
    CRC[2] = CRC[1] ^ invert;
    CRC[1] = CRC[0] ^ invert;
    CRC[0] = invert;
  }
}

// CRC function, used as a checksum for the data send to the laptop
int genCRC(byte* arr, int len, int replyTo)
{
  bool CRC[8];
  bool addLength = needsLength(replyTo);
  
  for (int i = 0; i < 8; ++i) CRC[i] = 0;
  
  iterateCRC(CRC, 22);
  iterateCRC(CRC, replyTo);
  iterateCRC(CRC, 23);
  
  if (addLength)
    iterateCRC(CRC, len);

  for (int x = 0; x < len; ++x) {
    int currentByte = arr[x];
    iterateCRC(CRC, currentByte);
  }

  int final = 0;

  for (int x = 0; x < 8; ++x)
    final += (0x01 << x) * CRC[x];

  // Serial.println(final);
  return final;
}

// Function signature for callbacks
// Takes byte array for a buffer and returns the number of bytes written to it
typedef byte (*smbusCallback)(byte*);

byte reply0x00(byte *buff) {
  buff[0] = 24;
  buff[1] = 0;
  return 2;
}

byte reply0x01(byte *buff) {
  buff[0] = 44;
  buff[1] = 1;
  return 2;
}

byte reply0x02(byte *buff) {
  buff[0] = 30;
  buff[1] = 0;
  return 2;
}

byte reply0x03(byte *buff) {
  buff[0] = 132;
  buff[1] = 128;

  return 2;
}

byte reply0x04(byte *buff) {
  buff[0] = 0;
  buff[1] = 0;
  return 2;
}

// 0x05

byte reply0x06(byte *buff) {
  buff[0] = 100;
  buff[1] = 0;

  return 2;
}

// 0x07

byte reply0x08(byte *buff) {
  buff[0] = 137;
  buff[1] = 11;

  return 2;
}

byte reply0x09(byte *buff) {
  int lower, higher;

  // Values of the resistors used in the voltage divider
  float r1 = 9.89;
  float r2 = 3.39;

  // Read the voltage divider input on analog pin that has a range of 3.33v to 0v, and output a number from 0 to 1024
  float voltageIn = analogRead(3) * (3.33 / 1024.0);
  float vin = voltageIn / (r2/(r1+r2)); 
  int Vinoff = vin * 1000;

  if (vin < 0)
    vin = 0;

  splitNum(Vinoff, &lower, &higher);
  buff[0] = lower;
  buff[1] = higher;

  return 2;
}

byte reply0x0a(byte *buff) {
  if (mode == 0) {
    buff[0] = 0;
    buff[1] = 0;
  } else {
    buff[0] = 0xF8;
    buff[1] = 0xFC;
  }

  return 2;
}

byte reply0x0b(byte *buff) {
  if (mode == 0) {
    buff[0] = 0;
    buff[1] = 0;
  } else {
    buff[0] = 0xF6;
    buff[1] = 0xFC;
  }

  return 2;
}

byte reply0x0c(byte *buff) {
  buff[0] = 0x00;
  buff[1] = 0x00;

  return 2;
}

// Relative state of charge
byte reply0x0d(byte *buff) {
  buff[0] = 0x5b;
  buff[1] = 0x00;

  return 2;
}

// 0x0e

byte reply0x0f(byte *buff) {
  int lower, higher;

  float r1 = 9.89;
  float r2 = 3.39;

  float sensorLow = V_LOW * (r2/(r1+r2));
  float sensorHigh = V_HIGH * (r2/(r1+r2));

  // Assume linear voltage -> battery capacity coorelation (this isn't perfect)
  // y = mx + b
  float m = 1/(sensorHigh - sensorLow);
  float b = -sensorLow*m;

  float voltageIn = analogRead(3) * (3.33 / 1024.0);
  int batteryVoltage = (m*voltageIn + b)*BATTERY_CAPACITY;

  if (batteryVoltage < 0)
    batteryVoltage = 0;

  splitNum(batteryVoltage, &lower, &higher);
  buff[0] = lower;
  buff[1] = higher;

  return 2;
}

byte reply0x10(byte *buff) {
  int lower, higher;
  
  splitNum(BATTERY_CAPACITY, &lower, &higher);
  buff[0] = lower;
  buff[1] = higher;
  
  return 2;
}

// Run time to empty
byte reply0x11(byte *buff) {
  buff[0] = 60;
  buff[1] = 0x00;

  return 2;
}

byte reply0x12(byte *buff) {
  buff[0] = 255;
  buff[1] = 255;

  return 2;
}

byte reply0x13(byte *buff) {
  buff[0] = 255;
  buff[1] = 255;

  return 2;
}

// 0x14-0x16

byte reply0x17(byte *buff) {
  buff[0] = 20;
  buff[1] = 5;

  return 2;
}

byte reply0x14(byte *buff) {
  buff[0] = 228;
  buff[1] = 12;

  return 2;
}

byte reply0x15(byte *buff) {
  int lower, higher;
  
  splitNum(CHARGE_VOLTAGE, &lower, &higher);
  buff[0] = lower;
  buff[1] = higher;

  return 2;
}

byte reply0x16(byte *buff) {
  buff[0] = 224;
  buff[1] = 192;

  return 2;
}

// 0x17

byte reply0x18(byte *buff) {
  int lower, higher;
  
  splitNum(BATTERY_CAPACITY_DESIGN, &lower, &higher);
  buff[0] = lower;
  buff[1] = higher;
  
  return 2;
}

byte reply0x19(byte *buff) {
  int lower, higher;
  
  splitNum(BATTERY_VOLTAGE, &lower, &higher);
  buff[0] = lower;
  buff[1] = higher;
  
  return 2;
}

byte reply0x1a(byte *buff) {
  buff[0] = 49;
  return 1;
}

byte reply0x1b(byte *buff) {
  buff[0] = 156;
  buff[1] = 61;
  return 2;
}

byte reply0x1c(byte *buff) {
  int lower, higher;
  
  splitNum(SERIAL, &lower, &higher);
  buff[0] = lower;
  buff[1] = higher;
  
  return 2;
}

// 0x1d-0x1f

byte reply0x20(byte *buff) {
  char *battery_vendor = BATTERY_VENDOR;

  for (int x = 0; x < strlen(battery_vendor); ++x) {
    buff[x] = battery_vendor[x];
  }

  int end = strlen(battery_vendor);
  
  buff[end + 0] = 0;
  buff[end + 1] = 49;
  buff[end + 2] = 49;

  return strlen(battery_vendor) + 3;
}

byte reply0x21(byte *buff) {
  char *battery_model = BATTERY_MODEL;

  for (int x = 0; x < strlen(battery_model); ++x) {
    buff[x] = battery_model[x];
  }

  return strlen(battery_model);
}

// Device chemistry
byte reply0x22(byte *buff) {
  buff[0] = 76;
  buff[1] = 73;
  buff[2] = 79;
  buff[3] = 78;

  return 4;
}

byte reply0x23(byte *buff) {
  buff[0] = 0x42;
  buff[1] = 0x0a;
  buff[2] = 0x05;
  buff[3] = 0x12;
  buff[4] = 0x86;
  buff[5] = 0x0f;
  buff[6] = 0x86;
  buff[7] = 0x0f;
  buff[8] = 0x86;
  buff[9] = 0x0f;
  buff[10] = 0x86;
  buff[11] = 0x0f;

  return 12;
}

// 0x24-0x2e

// ?
byte reply0x2f(byte *buff) {
  buff[0] = 49;
  buff[1] = 90;
  buff[2] = 74;
  buff[3] = 51;
  buff[4] = 74;
  buff[5] = 49;
  buff[6] = 49;
  buff[7] = 77;
  buff[8] = 49;
  buff[9] = 50;
  buff[10] = 88;

  return 11;
}

byte reply0x30(byte *buff) {
  buff[0] = 112;
  buff[1] = 156;
  buff[2] = 191;
  buff[3] = 25;
  buff[4] = 132;
  buff[5] = 74;
  buff[6] = 151;
  buff[7] = 0;
  buff[8] = 11;
  buff[9] = 0;

  return 10;
}

// 0x31-0x34

// ?
byte reply0x35(byte *buff) {
  buff[0] = 64;
  buff[1] = 0;

  return 2;
}

// 0x36

// ?
byte reply0x37(byte *buff) {
  buff[0] = 4;
  buff[1] = 0;
  buff[2] = 61;
  buff[3] = 94;
  buff[4] = 97;
  buff[5] = 1;
  buff[6] = 64;
  buff[7] = 1;

  return 8;
}

// 0x38-0x3a

byte reply0x3b(byte *buff) {
  buff[0] = 135;
  buff[1] = 11;

  return 2;
}

byte reply0x3c(byte *buff) {
  buff[0] = 76;
  buff[1] = 101;
  buff[2] = 110;
  buff[3] = 111;
  buff[4] = 118;
  buff[5] = 111;
  buff[6] = 32;
  buff[7] = 74;
  buff[8] = 97;
  buff[9] = 112;
  buff[10] = 97;
  buff[11] = 110;
  buff[12] = 145;
  buff[13] = 46;
  buff[14] = 93;
  buff[15] = 230;

  return 16;
}

byte reply0x3d(byte *buff) {
  buff[0] = 136;
  buff[1] = 11;

  return 2;
}

byte reply0x3e(byte *buff) {
  buff[0] = 1;
  buff[1] = 0;

  return 2;
}

byte reply0x3f(byte *buff) {
  buff[0] = 47;
  buff[1] = 79;

  return 2;
}


// Store a mapping of bytes to functions
// index 0 is used to reply to byte command 0, index 1 is used to reply to byte command 1, etc.
// NULL values are functions that are commands that are not used or have not been implemented
// See https://www.nxp.com/docs/en/application-note/AN4471.pdf for more information about what each command does

// Each of these functions will write to the global buffer and return the amount of bytes written
byte (* funMap [])(byte*) = {
  reply0x00,
  reply0x01,
  reply0x02,
  reply0x03,
  reply0x04,
  NULL,
  reply0x06,
  NULL,
  reply0x08,
  reply0x09,
  reply0x0a,
  reply0x0b,
  reply0x0c,
  reply0x0d,
  NULL,
  reply0x0f,
  reply0x10,
  reply0x11,
  reply0x12,
  reply0x13,
  reply0x14,
  reply0x15,
  reply0x16,
  reply0x17,
  reply0x18,
  reply0x19,
  reply0x1a,
  reply0x1b,
  reply0x1c,
  NULL,
  NULL,
  NULL,
  reply0x20,
  reply0x21,
  reply0x22,
  reply0x23,
  NULL,
  NULL,
  NULL,
  NULL,
  NULL,
  NULL,
  NULL,
  NULL,
  NULL,
  NULL,
  NULL,
  reply0x2f,
  reply0x30,
  NULL,
  NULL,
  NULL,
  NULL,
  reply0x35,
  NULL,
  reply0x37,
  NULL,
  NULL,
  NULL,
  reply0x3b,
  reply0x3c,
  reply0x3d,
  reply0x3e,
  reply0x3f
};

// Used to store replies to commands
byte buffGlobal[60];

void setup() {
  pinMode(PB3, INPUT);
  
  pinMode(PB4, OUTPUT);
  digitalWrite(PB4, LOW);
  
  command = 0;
  
  Wire.begin (0x0B);
  Wire.onReceive (receiveEvent);
  Wire.onRequest (requestEvent);
}

void loop() {
  unsigned long currentMillis = millis();
  
  delay(1);
}

// Read command send from laptop
void receiveEvent (uint8_t howMany)
{
  // Set command
  command = Wire.read();
  
  // Ignore bytes other than the first one. No commands currently require more than one byte
  for (int x = 0; x < howMany-1; x++) {
    byte a = Wire.read();
  }
}

// Write information and send it to laptop
void requestEvent () {
  // Look up the callback associated with the current command, NULL if no match is found
  smbusCallback callback = funMap[command];

  // No matching callback was found, return without further processing
  if (callback == null)
    return;

  // Call matching callback, which writes to the global buffer and returns the amount of bytes written
  int len = callback(buffGlobal);

  // Some commands require their length to be added. See needsLength function for a list of these commands
  // This length command is sent first, before all the data
  if (needsLength(command))
    Wire.write(len);
  
  // Write all bytes from the buffer
  for (int y = 0; y < len; ++y) {
    Wire.write(buffGlobal[y]);
  }

  // Generate and write the CRC. This is a checksum used to ensure communication works as intended
  Wire.write(genCRC(buffGlobal, len, command));
}

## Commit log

2020-08-28 Use PB4 to pull T pin low instead of PB5
    [battery-B_Cu.gbr, battery-B_Mask.gbr, battery-B_SilkS.gbr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]
2020-08-31 Add 3d model of case
    [CE3PRO_top.3mf, case.FCStd, top.stl]
2020-09-01 Add locking mechanism to case model
    [case.FCStd]
2020-09-01 Modify locking mechanism to work better
    [case.FCStd, lock.stl]
2020-09-03 Work on making latching mechansim spring back
    [bottom.stl, case.FCStd]
2020-09-04 Improve battery model
    [bottom.stl, case.FCStd, lock.stl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]
2020-09-06 better pcb
    [battery.kicad_pcb, battery.sch]
2020-09-12 Redesign latch mechanism
    [bottom.stl, case.FCStd]
2020-09-27 Finalize designs
    [bottom.stl, case.FCStd, lock.stl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]
2020-09-29 Finish model
    [CE3PRO_top.3mf, bottom.stl, case.FCStd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]
2020-09-29 Add stl files
    [back.stl, bottom.stl, bottom_case.stl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]
2020-09-29 Smooth out edges
    [bottom_case.stl, case.FCStd, top_case.stl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]
2020-09-29 Split up flat surfaces
    [bottom_case.stl, bottom_case_long.stl, case.FCStd]
2020-09-30 Decrease voltage limit low
2020-09-30 Make battery 162wh
    [case.FCStd, top_case_long.stl]
2020-10-04 Glitch T pin for charging
    [batteryEmulator.ino]
2020-10-10 Update PCB before manufacturing
    [battery.kicad_pcb, battery.sch]
2021-04-25 Update batteryEmulator.ino
    R50 support
2021-05-21 R1 bq3060
    [battery.kicad_pcb, bq3060.kicad_pcb, bq3060.sch]
2021-05-21 Finish bq3060 schematic
    [bq3060.sch]
2021-05-22 Routing attempt
    [bq3060.kicad_pcb, bq3060.sch]
2021-06-22 Tried routing again
    [bq3060.kicad_pcb]
2021-07-23 Comment batteryEmulator.ino
2021-07-23 Add prototype bq3060 design
    [bq3060.kicad_pcb, bq3060.sch]
2022-04-30 Handle case where SMBus command is not implemented
    NULL is returned from the function map for not-yet-implemented commands. Previously this would result in attempting to call `0()`, which is invalid. This change instead simply skips unimplemented commands.
    See https://onlinegdb.com/BZmJknxpB for a minimal working example.
    [batteryEmulator.ino]
2022-05-08 Order callbacks by hex value and mark missing
    This lines the functions up with the documentation the reader is consulting, which makes the code easier to navigate.
    It also adds comments to mark where the missing callbacks should go.
    I realize this is a massive lineno change; feel free to copy-paste into your own commit.
    [batteryEmulator.ino]

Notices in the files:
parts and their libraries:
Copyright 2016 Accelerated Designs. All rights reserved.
